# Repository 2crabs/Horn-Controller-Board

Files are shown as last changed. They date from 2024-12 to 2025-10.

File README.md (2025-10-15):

# Horn Controller v0.1

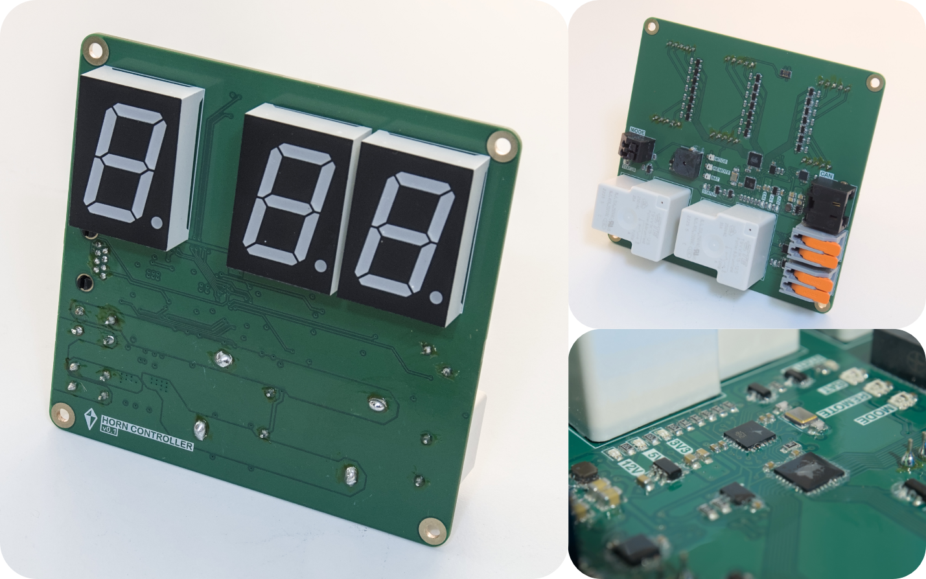
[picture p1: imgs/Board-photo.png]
Photo of Assembled PCB

Controller board for signal horns on a sailing race course and designed for reliability and easy integration. The board includes features such as ...

* __Current-sensing__: Current sensor at output of relays for making sure that motor is connected and running
* __Multiple Relays__: Two relays combined with logic to account for one of the relays failing
* __Large Display__: Large seven segment displays making it easy to see the countdown from a distance
* __Wago Connectors__: Easy to conect the power and motor wires, without the need to crimp on any connectors
* __CAN Bus__: Reliable and flexible communication with a remote control

## Resources
[Schematic](Schematic.pdf)

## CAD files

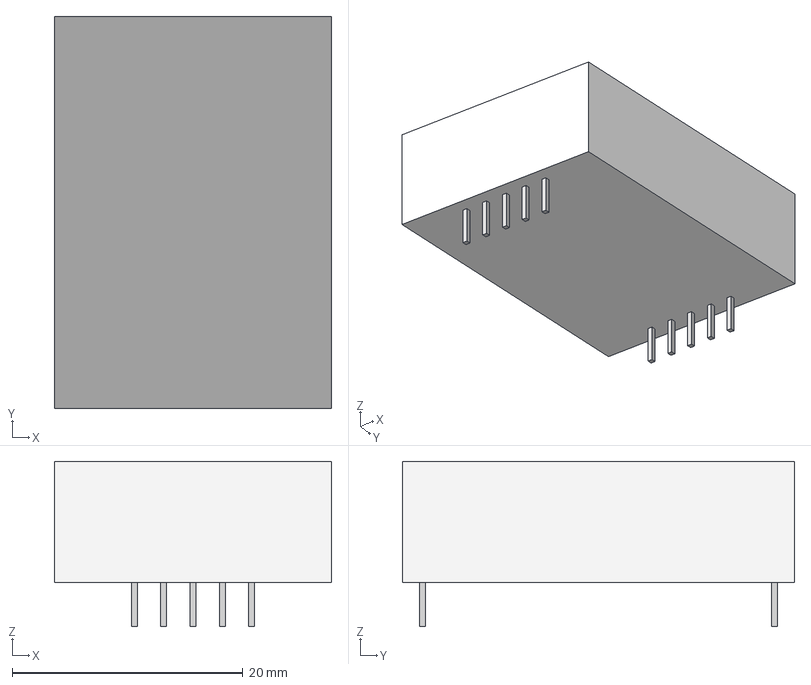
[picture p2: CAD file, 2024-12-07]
Display.step
24.0 x 34.0 x 14.3 mm

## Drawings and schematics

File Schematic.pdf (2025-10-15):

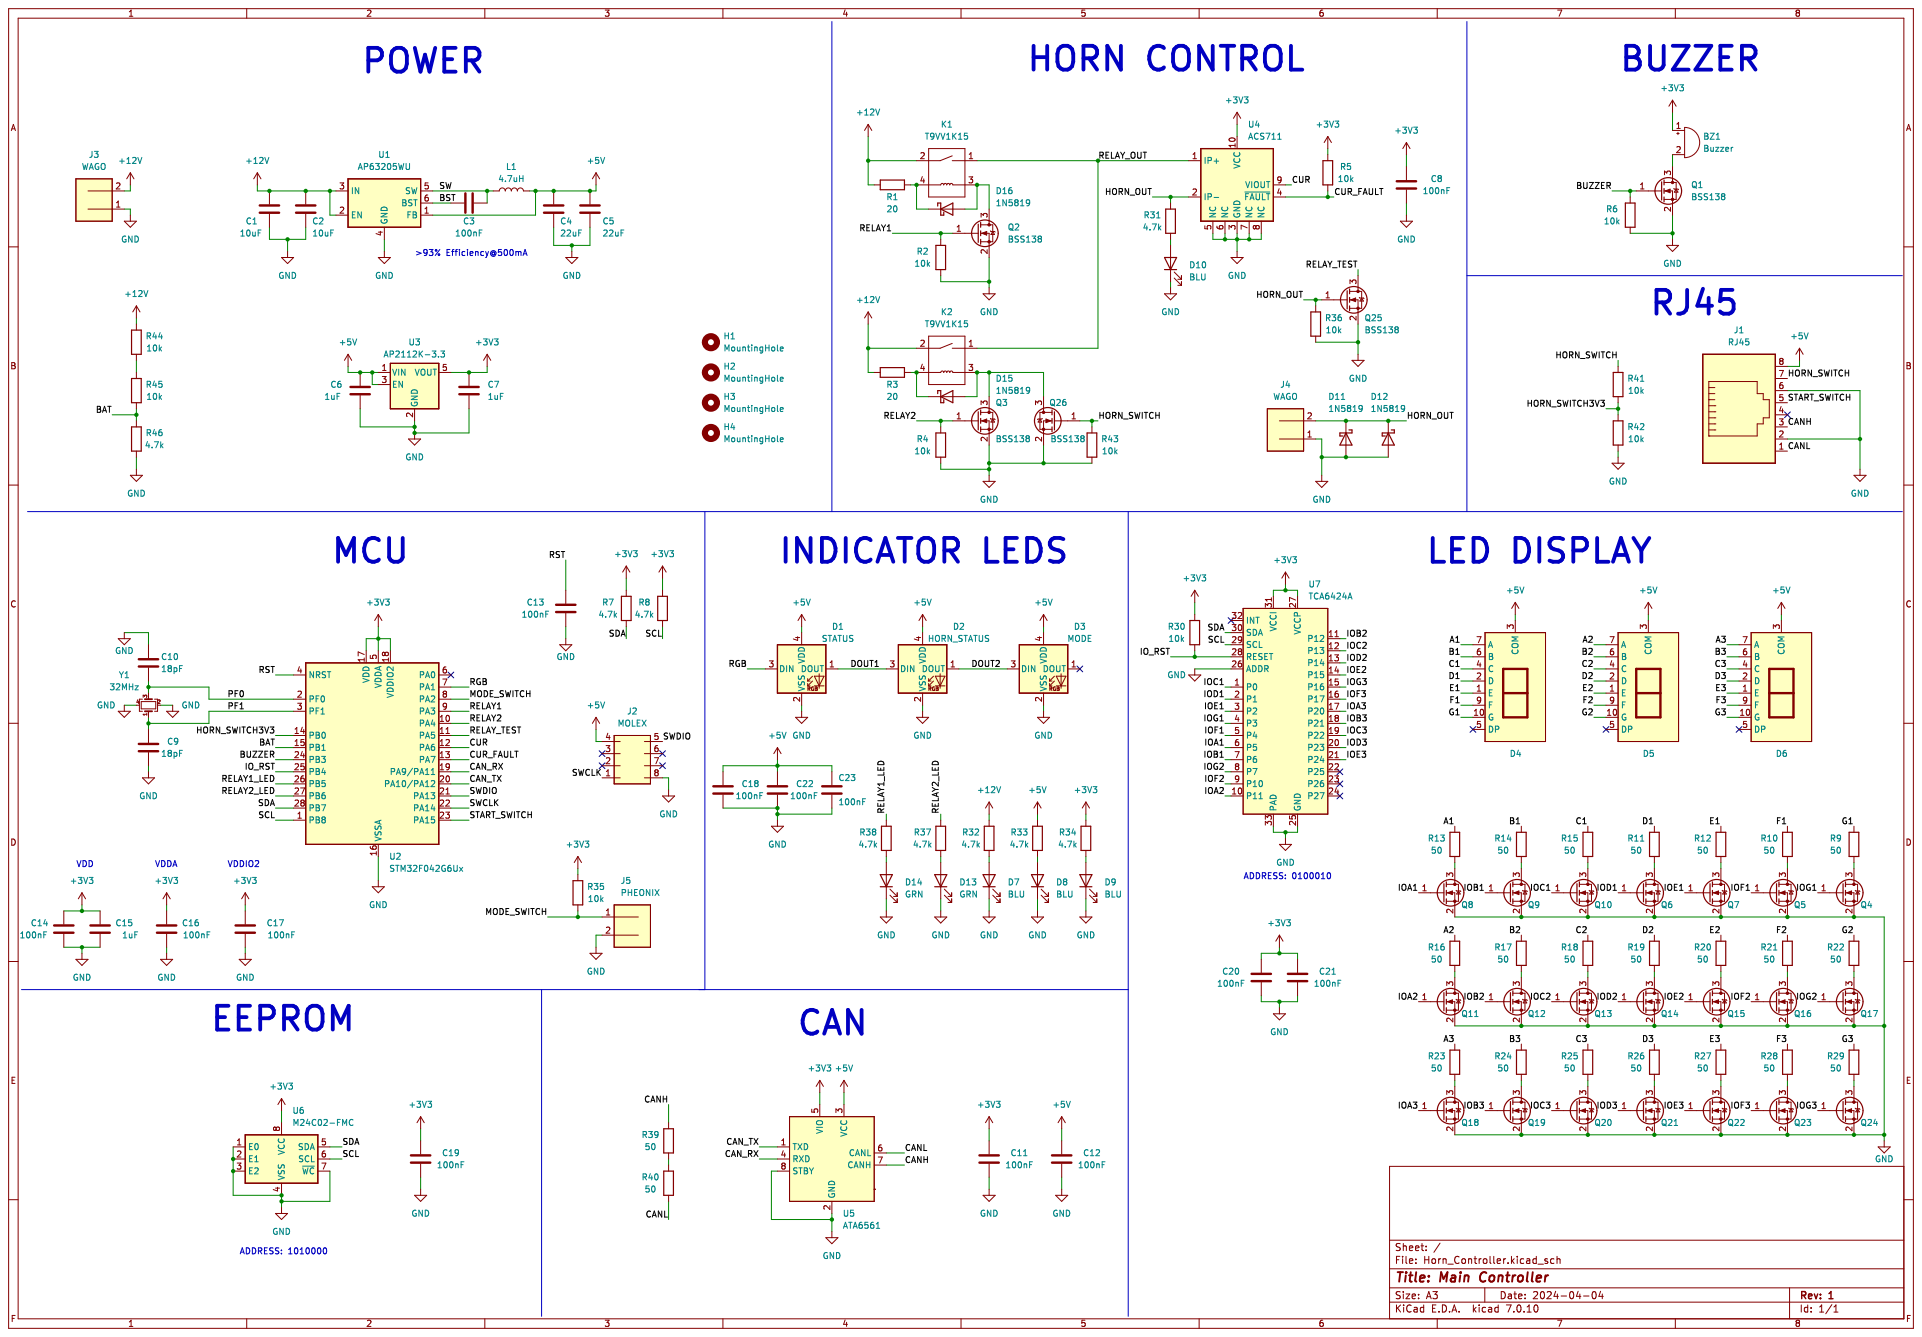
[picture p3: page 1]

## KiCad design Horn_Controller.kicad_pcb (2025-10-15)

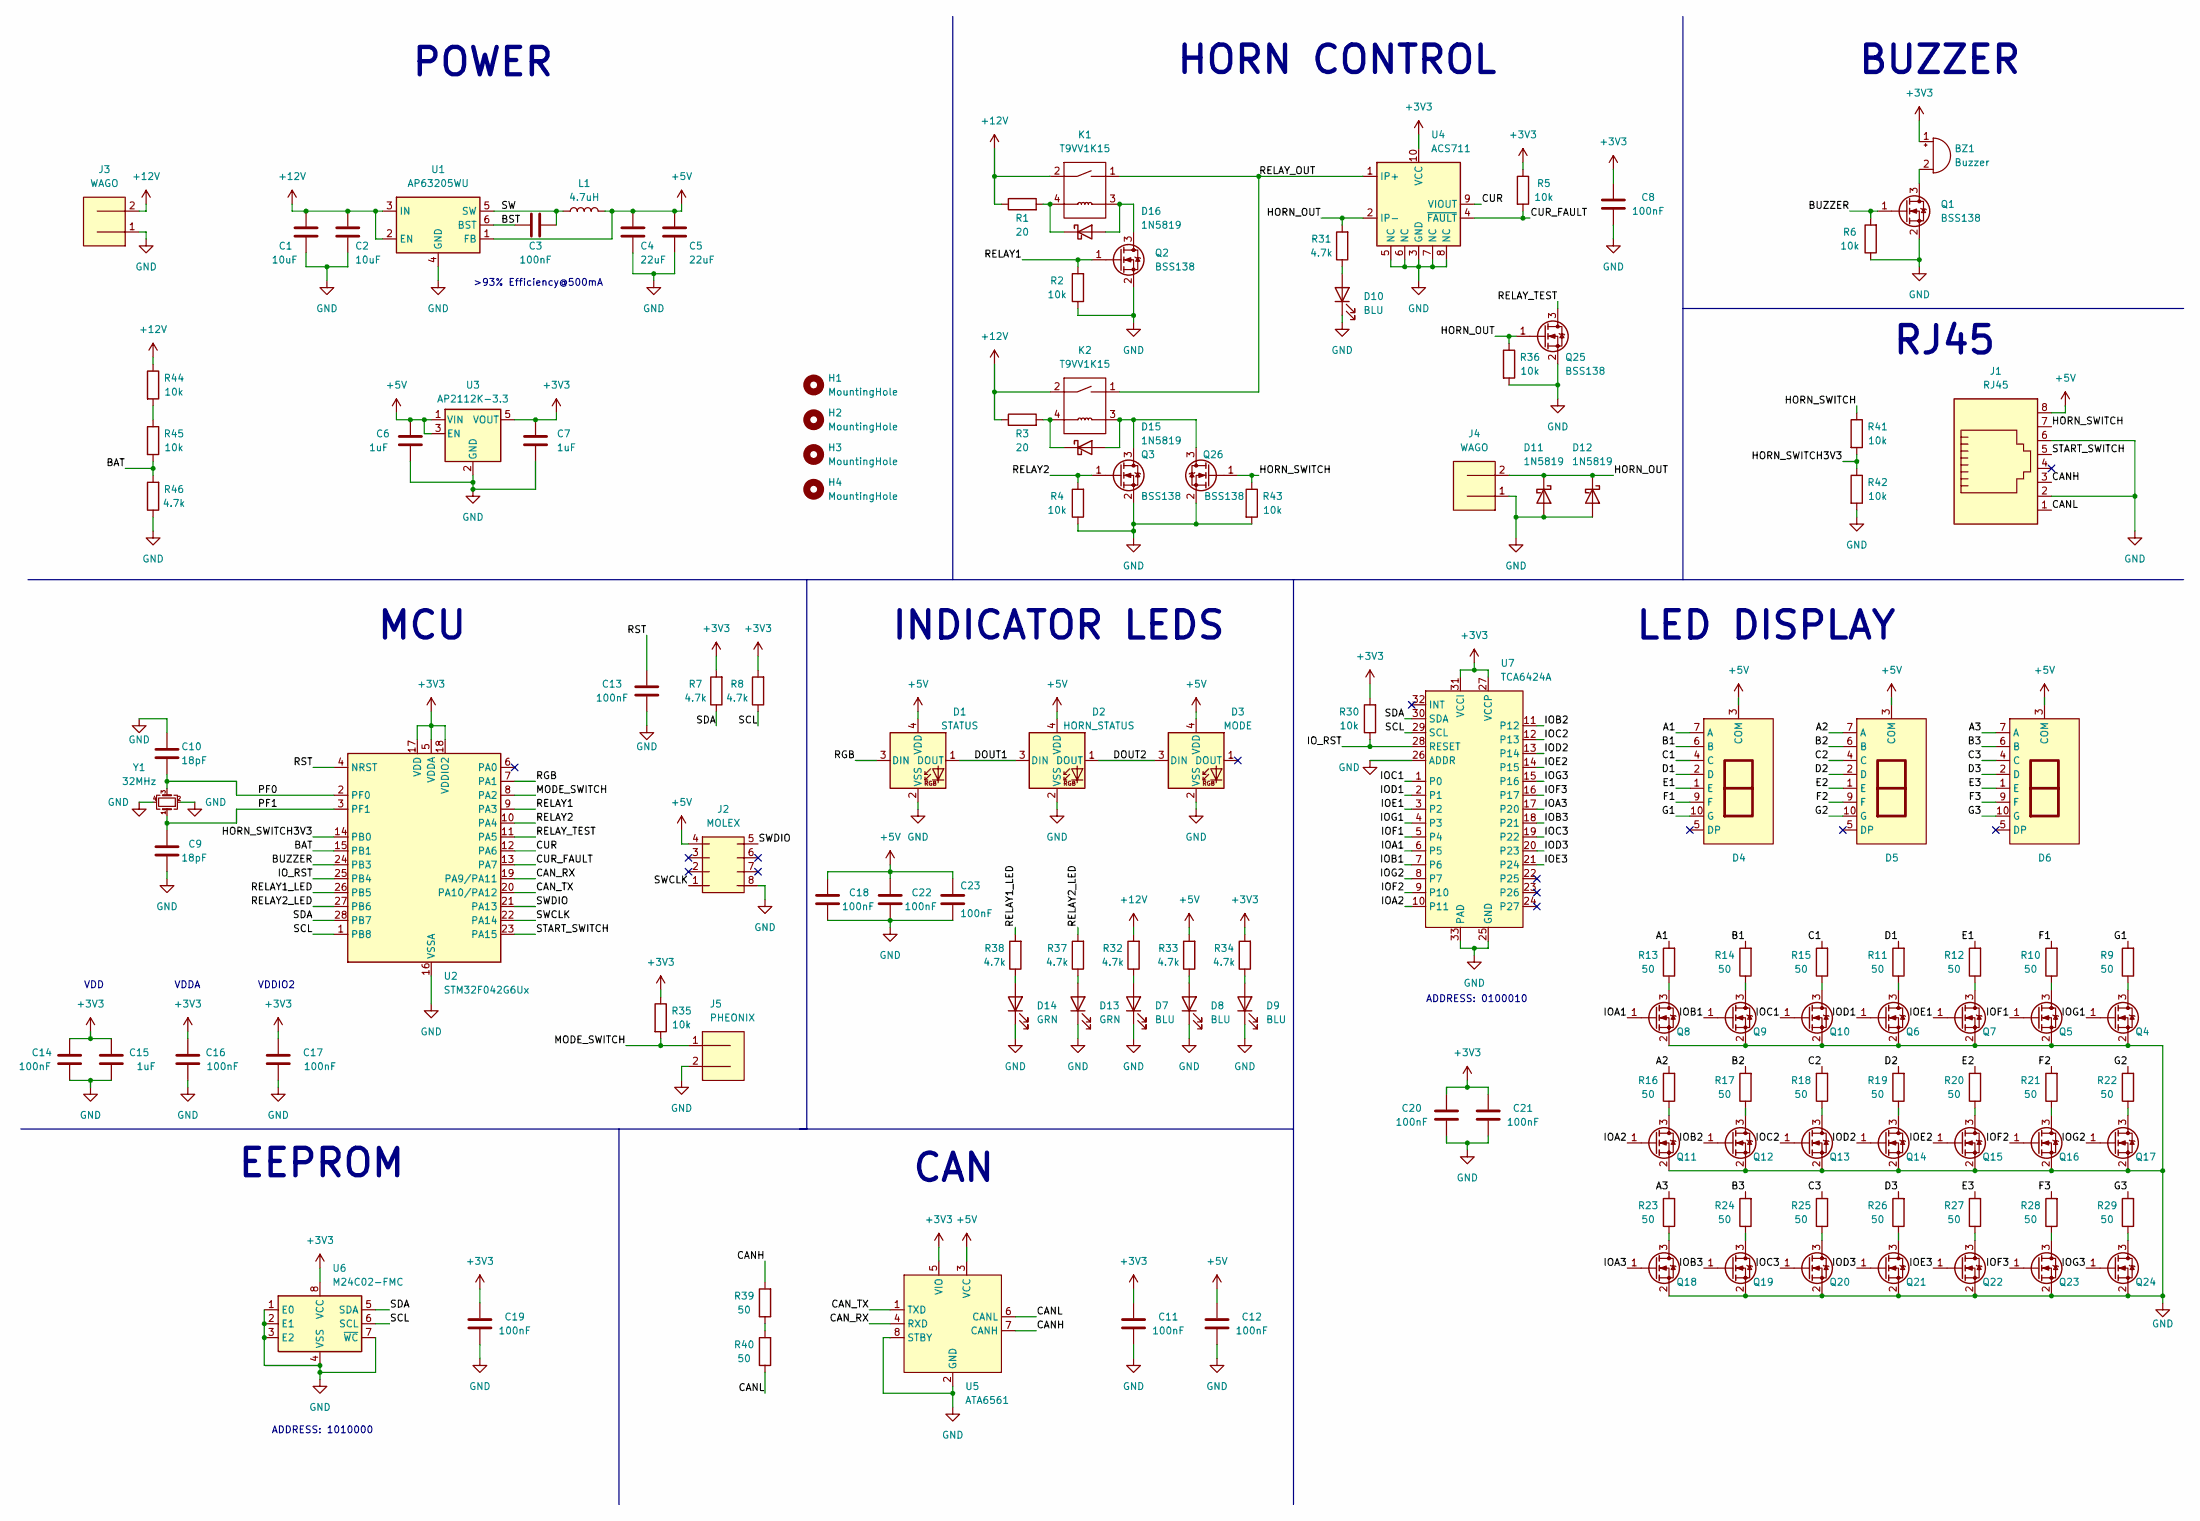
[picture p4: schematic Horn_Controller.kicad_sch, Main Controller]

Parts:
BZ1: Buzzer; CUI_CMI-9705-0380-SMT-TR
C1, C2: 10uF; C_0805_2012Metric
C3, C8, C11, C12, C13, C14, C16, C17, C18, C19, C20, C21, C22, C23: 100nF; C_0402_1005Metric
C4, C5: 22uF; C_0805_2012Metric
C6, C7, C15: 1uF; C_0603_1608Metric
C9, C10: 18pF; C_0603_1608Metric
D1: STATUS; WS2812B-2020
D2: HORN_STATUS; WS2812B-2020
D3: MODE; WS2812B-2020
D4, D5, D6: ARKLED-1IN
D7, D8, D9, D10: BLU; LED_0603_1608Metric
D11, D12, D15, D16: 1N5819; D_SOD-123
D13, D14: GRN; LED_0603_1608Metric
H1, H2, H3, H4: MountingHole; MountingHole_3.2mm_M3_Pad
J1: RJ45; rj45
J2: MOLEX; 5050040812-MOLEX
J3, J4: WAGO; 2604-WAGO
J5: PHEONIX; 1751765-Pheonix
K1, K2: T9VV1K15; T9V-Relay
L1: 4.7uH; L_1008_2520Metric
Q1, Q2, Q3, Q4, Q5, Q6, Q7, Q8, Q9, Q10, Q11, Q12, Q13, Q14, Q15, Q16, Q17, Q18, Q19, Q20, Q21, Q22, Q23, Q24, Q25, Q26: BSS138; SOT-23
R1, R3: 20; R_2512_6332Metric
R2, R4, R5, R6, R30, R35, R36, R41, R42, R43, R44, R45: 10k; R_0603_1608Metric
R7, R8, R31, R32, R33, R34, R37, R38, R46: 4.7k; R_0603_1608Metric
R9, R10, R11, R12, R13, R14, R15, R16, R17, R18, R19, R20, R21, R22, R23, R24, R25, R26, R27, R28, R29, R39, R40: 50; R_0603_1608Metric
U1: AP63205WU; TSOT-23-6
U2: STM32F042G6Ux; QFN-28_4x4mm_P0.5mm
U3: AP2112K-3.3; SOT-23-5
U4: ACS711; Allegro_QFN-12-10-1EP_3x3mm_P0.5mm
U5: ATA6561; DFN-8-1EP_3x3mm_P0.65mm_EP1.7x2.05mm
U6: M24C02-FMC; 8-UFDFPN
U7: TCA6424A; VQFN-32-1EP_5x5mm_P0.5mm_EP3.15x3.15mm_ThermalVias
Y1: 32MHz; Crystal_SMD_3225-4Pin_3.2x2.5mm

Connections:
+3V3: BZ1.1 (+), C7.1, C8.1, C11.1, C14.1, C15.1, C16.1, C17.1, C19.1, C20.1, C21.1, R5.1, R7.2, R8.2, R30.2, R34.2, R35.1, U2.5 (VDDA), U2.17 (VDD), U2.18 (VDDIO2), U3.5 (VOUT), U4.10 (VCC), U5.5 (VIO), U6.8 (VCC), U7.27 (VCCP), U7.31 (VCCI)
+5V: C4.1, C5.1, C6.1, C12.1, C18.1, C22.1, C23.1, D1.4 (VDD), D2.4 (VDD), D3.4 (VDD), D4.3 (COM), D5.3 (COM), D6.3 (COM), J1.8, J2.4, L1.2, R33.2, U1.1 (FB), U3.1 (VIN), U3.3 (EN), U5.3 (VCC)
+12V: C1.1, C2.1, J3.2, K1.2, K2.2, R1.1, R3.1, R32.2, R44.1, U1.2 (EN), U1.3 (IN)
/A1: D4.7 (A), R13.2
/A2: D5.7 (A), R16.2
/A3: D6.7 (A), R23.2
/B1: D4.6 (B), R14.2
/B2: D5.6 (B), R17.2
/B3: D6.6 (B), R24.2
/BAT: R45.2, R46.2, U2.15 (PB1)
/BST: C3.2, U1.6 (BST)
/BUZZER: Q1.1 (G), R6.2, U2.24 (PB3)
/C1: D4.4 (C), R15.2
/C2: D5.4 (C), R18.2
/C3: D6.4 (C), R25.2
/CANH: J1.3, R39.2, U5.7 (CANH)
/CANL: J1.1, R40.1, U5.6 (CANL)
/CAN_RX: U2.19 (PA9/PA11), U5.4 (RXD)
/CAN_TX: U2.20 (PA10/PA12), U5.1 (TXD)
/CUR: U2.12 (PA6), U4.9 (VIOUT)
/CUR_FAULT: R5.2, U2.13 (PA7), U4.4 (~FAULT)
/D1: D4.2 (D), R11.2
/D2: D5.2 (D), R19.2
/D3: D6.2 (D), R26.2
/DOUT1: D1.1 (DOUT), D2.3 (DIN)
/DOUT2: D2.1 (DOUT), D3.3 (DIN)
/E1: D4.1 (E), R12.2
/E2: D5.1 (E), R20.2
/E3: D6.1 (E), R27.2
/F1: D4.9 (F), R10.2
/F2: D5.9 (F), R21.2
/F3: D6.9 (F), R28.2
/G1: D4.10 (G), R9.2
/G2: D5.10 (G), R22.2
/G3: D6.10 (G), R29.2
/HORN_OUT: D11.1 (K), D12.1 (K), J4.2, Q25.1 (G), R31.2, R36.1, U4.2 (IP-)
/HORN_SWITCH: J1.7, Q26.1 (G), R41.1, R43.1
/HORN_SWITCH3V3: R41.2, R42.1, U2.14 (PB0)
/IOA1: Q8.1 (G), U7.6 (P5)
/IOA2: Q11.1 (G), U7.10 (P11)
/IOA3: Q18.1 (G), U7.17 (P20)
/IOB1: Q9.1 (G), U7.7 (P6)
/IOB2: Q12.1 (G), U7.11 (P12)
/IOB3: Q19.1 (G), U7.18 (P21)
/IOC1: Q10.1 (G), U7.1 (P0)
/IOC2: Q13.1 (G), U7.12 (P13)
/IOC3: Q20.1 (G), U7.19 (P22)
/IOD1: Q6.1 (G), U7.2 (P1)
/IOD2: Q14.1 (G), U7.13 (P14)
/IOD3: Q21.1 (G), U7.20 (P23)
/IOE1: Q7.1 (G), U7.3 (P2)
/IOE2: Q15.1 (G), U7.14 (P15)
/IOE3: Q22.1 (G), U7.21 (P24)
/IOF1: Q5.1 (G), U7.5 (P4)
/IOF2: Q16.1 (G), U7.9 (P10)
/IOF3: Q23.1 (G), U7.16 (P17)
/IOG1: Q4.1 (G), U7.4 (P3)
/IOG2: Q17.1 (G), U7.8 (P7)
/IOG3: Q24.1 (G), U7.15 (P16)
/IO_RST: R30.1, U2.25 (PB4), U7.28 (RESET)
/MODE_SWITCH: J5.1, R35.2, U2.8 (PA2)
/PF0: C10.2, U2.2 (PF0), Y1.3
/PF1: C9.1, U2.3 (PF1), Y1.1
/RELAY1: Q2.1 (G), R2.2, U2.9 (PA3)
/RELAY1_LED: R38.2, U2.26 (PB5)
/RELAY2: Q3.1 (G), R4.2, U2.10 (PA4)
/RELAY2_LED: R37.2, U2.27 (PB6)
/RELAY_OUT: K1.1, K2.1, U4.1 (IP+)
/RELAY_TEST: Q25.3 (D), U2.11 (PA5)
/RGB: D1.3 (DIN), U2.7 (PA1)
/RST: C13.1, U2.4 (NRST)
/SCL: R8.1, U2.1 (PB8), U6.6 (SCL), U7.29 (SCL)
/SDA: R7.1, U2.28 (PB7), U6.5 (SDA), U7.30 (SDA)
/START_SWITCH: J1.5, U2.23 (PA15)
/SW: C3.1, L1.1, U1.5 (SW)
/SWCLK: J2.1, U2.22 (PA14)
/SWDIO: J2.5, U2.21 (PA13)
GND: C1.2, C2.2, C4.2, C5.2, C6.2, C7.2, C8.2, C9.2, C10.1, C11.2, C12.2, C13.2, C14.2, C15.2, C16.2, C17.2, C18.2, C19.2, C20.2, C21.2, C22.2, C23.2, D1.2 (VSS), D2.2 (VSS), D3.2 (VSS), D7.1 (K), D8.1 (K), D9.1 (K), D10.1 (K), D11.2 (A), D12.2 (A), D13.1 (K), D14.1 (K), J1.2, J1.6, J2.8, J3.1, J4.1, J5.2, Q1.2 (S), Q2.2 (S), Q3.2 (S), Q4.2 (S), Q5.2 (S), Q6.2 (S), Q7.2 (S), Q8.2 (S), Q9.2 (S), Q10.2 (S), Q11.2 (S), Q12.2 (S), Q13.2 (S), Q14.2 (S), Q15.2 (S), Q16.2 (S), Q17.2 (S), Q18.2 (S), Q19.2 (S), Q20.2 (S), Q21.2 (S), Q22.2 (S), Q23.2 (S), Q24.2 (S), Q25.2 (S), Q26.2 (S), R2.1, R4.1, R6.1, R36.2, R42.2, R43.2, R46.1, U1.4 (GND), U2.16 (VSSA), U3.2 (GND), U4.3 (GND), U4.5 (NC), U4.6 (NC), U4.7 (NC), U4.8 (NC), U5.2 (GND), U5.8 (STBY), U5.9, U6.1 (E0), U6.2 (E1), U6.3 (E2), U6.4 (VSS), U6.7 (~WC), U7.25 (GND), U7.26 (ADDR), U7.33 (PAD), Y1.2, Y1.4
unnamed: BZ1.2 (-), Q1.3 (D)
unnamed: D7.2 (A), R32.1
unnamed: D8.2 (A), R33.1
unnamed: D9.2 (A), R34.1
unnamed: D10.2 (A), R31.1
unnamed: D13.2 (A), R37.1
unnamed: D14.2 (A), R38.1
unnamed: D15.2 (A), K2.3, Q3.3 (D), Q26.3 (D)
unnamed: D15.1 (K), K2.4, R3.2
unnamed: D16.2 (A), K1.3, Q2.3 (D)
unnamed: D16.1 (K), K1.4, R1.2
unnamed: Q4.3 (D), R9.1
unnamed: Q5.3 (D), R10.1
unnamed: Q6.3 (D), R11.1
unnamed: Q7.3 (D), R12.1
unnamed: Q8.3 (D), R13.1
unnamed: Q9.3 (D), R14.1
unnamed: Q10.3 (D), R15.1
unnamed: Q11.3 (D), R16.1
unnamed: Q12.3 (D), R17.1
unnamed: Q13.3 (D), R18.1
unnamed: Q14.3 (D), R19.1
unnamed: Q15.3 (D), R20.1
unnamed: Q16.3 (D), R21.1
unnamed: Q17.3 (D), R22.1
unnamed: Q18.3 (D), R23.1
unnamed: Q19.3 (D), R24.1
unnamed: Q20.3 (D), R25.1
unnamed: Q21.3 (D), R26.1
unnamed: Q22.3 (D), R27.1
unnamed: Q23.3 (D), R28.1
unnamed: Q24.3 (D), R29.1
unnamed: R39.1, R40.2
unnamed: R44.2, R45.1

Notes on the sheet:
HORN CONTROL
EEPROM
INDICATOR LEDS
ADDRESS: 0100010
CAN
VDD
LED DISPLAY
ADDRESS: 1010000
VDDIO2
>93% Efficiency@500mA
BUZZER
RJ45
POWER
VDDA
MCU

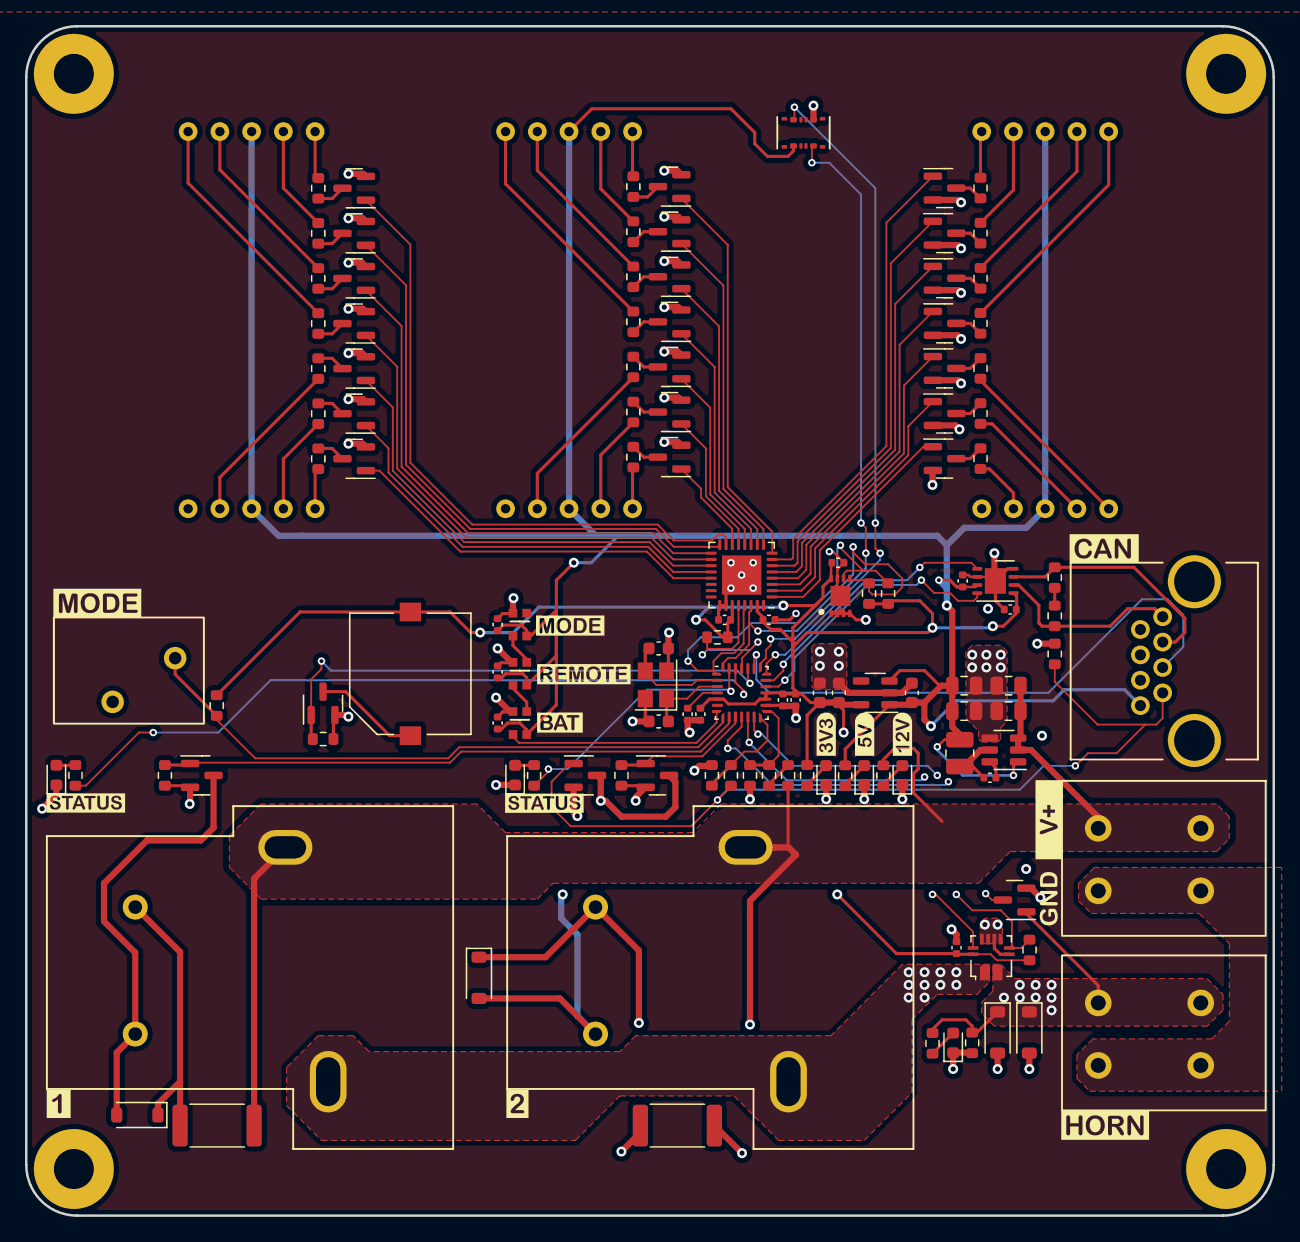
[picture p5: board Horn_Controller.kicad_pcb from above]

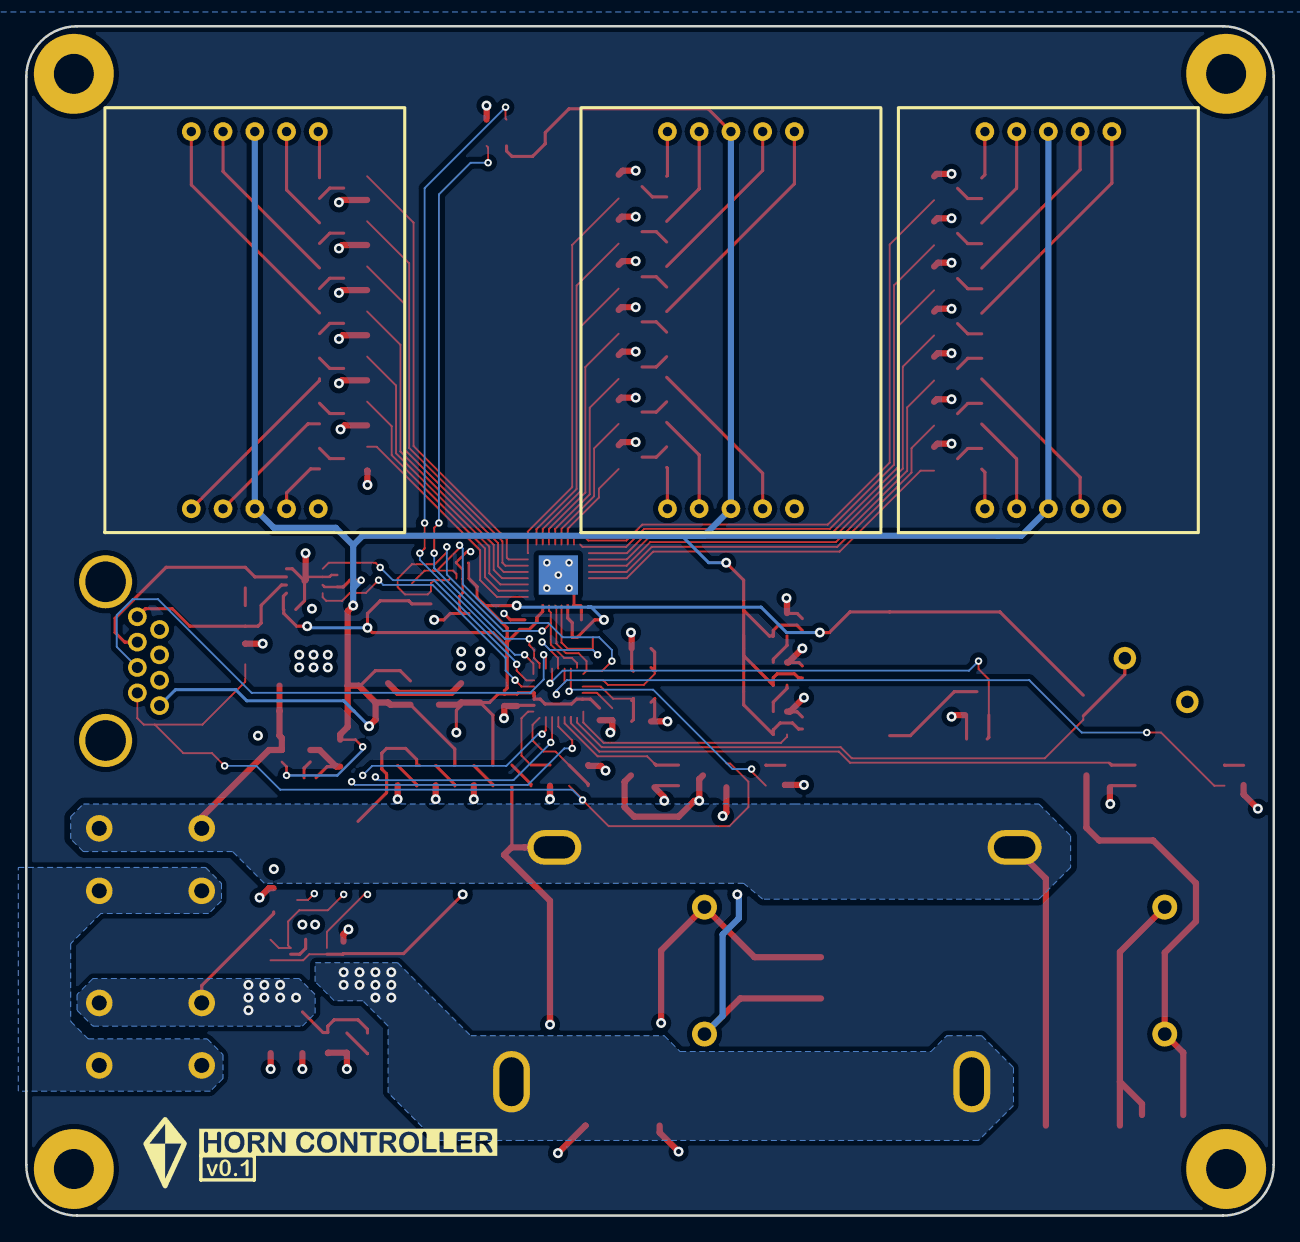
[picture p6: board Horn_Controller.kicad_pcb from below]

Board: 4 copper layers, 99.8 x 95.2 mm, 132 parts (3 on the bottom side), 112 nets.

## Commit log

2024-12-07 Project files
    [Display.step, Horn_Controller.kicad_pcb, Horn_Controller.kicad_sch]
2025-10-15 Added missing I2C trace
    [Horn_Controller.kicad_pcb]
2025-10-15 Schematic readability changes
    [Horn_Controller.kicad_sch]
2025-10-15 Added Schematic PDF
